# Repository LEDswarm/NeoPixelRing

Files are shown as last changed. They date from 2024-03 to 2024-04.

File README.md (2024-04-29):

led_board_banner3

# A custom NeoPixel ring for LEDswarm controllers

This repository contains the 3D model, schematic and PCB design of the circular NeoPixel boards designed for use with the LEDswarm controller enclosure. The design is inspired by NeoPixel Jewels, except this a special daughter board designed to mate with controller mainboards within [the 3D-printed enclosure](https://github.com/LEDswarm/enclosure).

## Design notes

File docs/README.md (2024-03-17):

# A custom NeoPixel ring with a board-to-board USB-C socket

A custom circular PCB with a ring of eight cool-white SK6812 RGBW LEDs on it, used to illuminate the diffusor of an LEDswarm controller enclosure.

Many of the first experiments were done with the NeoPixel Jewels by Adafruit, which is basically a short LED strip of seven NeoPixels arranged in a hexagon and with one in the middle. However, that board turned out to be not easily adaptable to a connector-based, board-to-board design, so we decided to use USB-C to mate the boards and directly use a few pins of a USB-C connection to transfer +5V, the data signal, ground and an optional I2C connection for additional peripherals.

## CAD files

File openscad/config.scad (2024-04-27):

/////
//     General configuration
/////

$fn = 96;

/////
//     PCB dimensions
/////

pcb_diameter = 28.5;
pcb_thickness = 1.6;

pcb_radius = pcb_diameter / 2;
pcb_color = [0.2, 0.2, 0.2];
// Height of the SMD pads on the circuit board
smd_pad_height = 0.035;


/////
//     PCB drill holes
/////

pcb_screw_diameter = 2.0;
pcb_screw_hole_diameter = 2.0;

// How far to inset the screw holes from the edge of the PCB
pcb_screw_hole_inset = 0.7;

/////
//     LED dimensions
/////

// Size is 5050, so five by five millimeters
led_size = 5.0;
led_height = 1.0;

// How many LEDs to place in the circle
num_leds = 8;
// Set rotation phase of the LEDs
led_starting_angle = (360 / num_leds) / 2;

// How far outwards to push the LEDs in their octagonal arrangement
led_radius= 20.3;

// How far outwards to put the capacitors
led_capacitor_length = 4 / 2.54;
led_capacitor_width = 2 / 2.54;
led_capacitor_height = 2 / 2.54;

led_capacitor_color = [0.7, 0.45, 0];

led_text_num_radius = 12.5;

led_capacitor_radius= 24.5;
led_capacitor_starting_angle = 45.0;
// Make sure to respect screw holes when placing eight possible capacitor spots on circle.
led_capacitor_distribution = [true, true, true, false, true, true, true, false];

// How many millimeters the pad is inset from the edge of the LED.
led_smd_pad_inset = 0.4;
// How many millimeters the square pad extends out to the side from the LED edge.
led_smd_pad_outset = 0.2;
led_smd_pad_width = 1.5;
led_smd_pad_height = 1.0;


/////
//     SMD mount dimensions for female USB-C socket
/////

// Ensures the vias are aligned to the through holes correctly.
via_correction_factor = 0.07;

// Vertical offset of the USB-C port from the center of the PCB, to accomodate for the breadboard pin vias.
male_usb_c_height = 2.4;
//usb_vertical_offset = pcb_thickness / 2 + male_usb_c_height / 2;
// The male connector is vertically centered.
usb_vertical_offset = 0;

echo("USB vertical offset: ", usb_vertical_offset);

// Pin hole size for the USB-C port
usb_pin_hole_diameter = 0.9;

// Distance between the centers of the two pin holes
usb_pin_hole_spacing = 10.8;

// Horizontal distance between the centers of two USB-C through-hole pins
usb_through_hole_horizontal_spacing = 8.45;
usb_through_hole_vertical_spacing = 4.04;

// Dimensions of the cut holes for the USB-C port
usb_through_hole_width = 1.85;
usb_through_hole_height = 1.0;
usb_through_hole_inner_width = 1.3;
usb_through_hole_inner_height = 0.6;
usb_through_hole_inner_border_radius = usb_through_hole_inner_height / 2;
usb_through_hole_border_radius = usb_through_hole_height / 2;

// Dimensions and extents of the SMD pads for the USB-C port
usb_smd_pad_height = 1.6;
usb_smd_pad_width = 0.55;
// Horizontal distance between the centers of two USB-C SMD pads
usb_smd_pad_horizontal_spacing = 1.0;
// How many pads to place for single contact row in the USB-C SMD connector
usb_smd_pad_num_h = 8;

// Total vertical extent of the USB SMD pads, or the distance from the top edge of an upper SMD pad to the bottom edge of a lower SMD pad.
usb_smd_vertical_extent = 3.9;
// Horizontal spacing between the centers of the outermost SMD contacts.
usb_smd_horizontal_spacing = 7.0;

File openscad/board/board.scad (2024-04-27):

include <../config.scad>;

include <../capacitor.scad>;
include <../smd/usb_contacts.scad>;

// The circular circuit board of the NeoPixel ring.
module BoardPcb () {
    difference () {
        union () {
            color(pcb_color)
            cylinder(d=pcb_diameter, h=pcb_thickness, center = true);
            
            translate([0, -usb_vertical_offset, 0])
            usb_smd();
        }

        BoardDrillHoles();
    }

    //LedCircularArrangement();
    //CapacitorCircularArrangement();
    //color([0.7, 0.3, 0.3])
    //LedSilkscreenCircularArrangement();
}

module BoardDrillHoles () {
    BoardScrewHole();

    mirror([1, 0, 0])
    BoardScrewHole();

    // usb_pin_hole_spacing
    BoardUsbPinhole();
    mirror([1, 0, 0])
    BoardUsbPinhole();

    translate([0, vertical_center, -3])
    usb_smd_corner_cutouts();
}

module BoardScrewHole () {
    echo("Screw hole at ", pcb_diameter / 2 - pcb_screw_hole_inset - pcb_screw_hole_diameter / 2, " 0 -1");
    translate([pcb_diameter / 2 - pcb_screw_hole_inset - pcb_screw_hole_diameter / 2, 0, -1])
    cylinder(d=pcb_screw_hole_diameter, h=pcb_thickness + 3, center = true);
}

module BoardUsbPinhole () {
    translate([usb_pin_hole_spacing / 2, -usb_vertical_offset, -1])
    cylinder(d=usb_pin_hole_diameter, h=pcb_thickness + 3, center = true);
}

module LedCircularArrangement () {
    for (i = [0 : num_leds - 1]) {
        current_angle = i * (360.0 / num_leds);
        x = led_radius / 2 * cos(led_starting_angle + current_angle);
        y = led_radius / 2 * sin(led_starting_angle + current_angle);
        echo("LED ", i, " at X ", x, "   Y ", y, "     Angle ", led_starting_angle + current_angle);

        translate([x, y, 0])
        led(rotation = led_starting_angle + current_angle);
    }
}

module CapacitorCircularArrangement () {
    for (i = [0 : num_leds - 1]) {
        current_angle = i * (360.0 / num_leds);
        x = led_capacitor_radius / 2 * cos(led_capacitor_starting_angle + current_angle);
        y = led_capacitor_radius / 2 * sin(led_capacitor_starting_angle + current_angle);

        echo("Capacitor ", i, " at X ", x, "   Y ", y, "     Angle ", led_capacitor_starting_angle + current_angle);

        if (led_capacitor_distribution[i]) {
            translate([x, y, 1.2])
            Capacitor(rotation = led_capacitor_starting_angle + current_angle);
        }
    }
}

led_vdd_via_circle_radius = 23.0;

module LedSilkscreenCircularArrangement () {
    for (i = [0 : num_leds - 1]) { // Condition: num_leds - 1
        current_angle = i * (360.0 / num_leds) + 180;
        x = led_vdd_via_circle_radius / 2 * cos(led_starting_angle + current_angle);
        y = led_vdd_via_circle_radius / 2 * sin(led_starting_angle + current_angle);

        echo("LED Silkscreen Number ", i, " at X ", x, "   Y ", y, "     Angle ", led_starting_angle - 20 + current_angle);

        translate([x - 0.2, y - 0.2, 0])
        cylinder(h=4, d=1);

        translate([x + 1.1, y - 3.1, 0])
        cylinder(h=4, d=1);
    }
}

module led (rotation = 0.0) {
    rotate(rotation, [0, 0, 1])
    translate([0, 0, pcb_thickness / 2])
    LED_5050_RGBW();
}

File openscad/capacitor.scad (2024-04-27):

module Capacitor (rotation = 0.0) {
    color(led_capacitor_color)
    rotate([0, 0, rotation])
    cube([led_capacitor_length, led_capacitor_width, led_capacitor_height], center=true);
}

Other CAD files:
openscad/led.scad
openscad/main.scad
openscad/smd/usb_contacts.scad

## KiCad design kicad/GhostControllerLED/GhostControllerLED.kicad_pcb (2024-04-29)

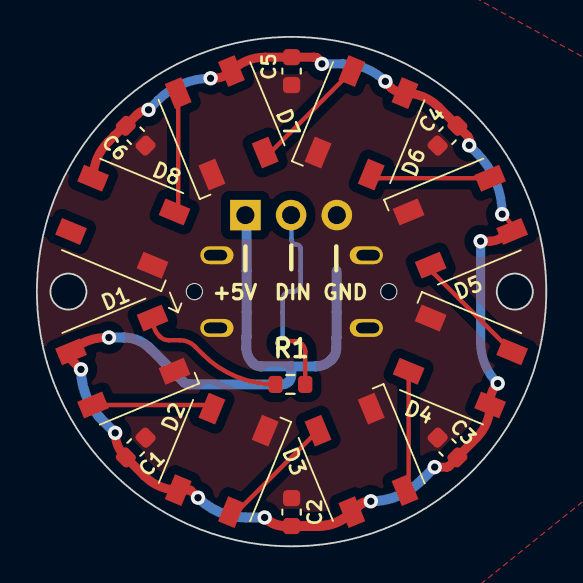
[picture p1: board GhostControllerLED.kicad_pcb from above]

Board: 2 copper layers, 28.3 x 28.3 mm, 16 parts (1 on the bottom side), 11 nets.

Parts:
1: SK6812; LED_SK6812_PLCC4_5.0x5.0mm_P3.2mm
C1, C2, C3, C4, C5, C6: 100nF; C_0603_1608Metric
D2, D3, D4, D5, D6, D7, D8: SK6812; LED_SK6812_PLCC4_5.0x5.0mm_P3.2mm
NoUSB: Female LED Connector (No USB); Hanbo-Electronic-MC-118LS-H100 USB-C Socket
R1: 220; R_0603_1608Metric

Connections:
GND: 1.1 (VSS), C1.1, C2.1, C3.1, C4.1, C5.1, C6.1, D2.1 (VSS), D3.1 (VSS), D4.1 (VSS), D5.1 (VSS), D6.1 (VSS), D7.1 (VSS), D8.1 (VSS), NoUSB.1, NoUSB.2, NoUSB.3, NoUSB.A1 (GND), NoUSB.A12 (GND), NoUSB.B1 (GND), NoUSB.B12 (GND)
unnamed: 1.2 (DIN), R1.1
unnamed: 1.4 (DOUT), D2.2 (DIN)
unnamed: 1.3 (VDD), C1.2, C2.2, C3.2, C4.2, C5.2, C6.2, D2.3 (VDD), D3.3 (VDD), D4.3 (VDD), D5.3 (VDD), D6.3 (VDD), D7.3 (VDD), D8.3 (VDD), NoUSB.A4 (VBUS), NoUSB.A9 (VBUS), NoUSB.B4 (VBUS), NoUSB.B9 (VBUS)
unnamed: D2.4 (DOUT), D3.2 (DIN)
unnamed: D3.4 (DOUT), D4.2 (DIN)
unnamed: D4.4 (DOUT), D5.2 (DIN)
unnamed: D5.4 (DOUT), D6.2 (DIN)
unnamed: D6.4 (DOUT), D7.2 (DIN)
unnamed: D7.4 (DOUT), D8.2 (DIN), D8.4 (DOUT)
unnamed: NoUSB.A6 (D+), NoUSB.B6 (D+), R1.2

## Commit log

2024-03-17 feat: start working on a structured approach to 3d modeling the neopixel board
    [board.scad, config.scad, led.scad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]
2024-03-17 feat: add programmatic distribution of leds around the tangential of a circle
    [board.scad]
2024-03-17 config: add PCB color and circle diameter for tangential LED placement
    [config.scad]
2024-03-17 chore: wrap led base into a module and mirror smd pins two by two
    [led.scad]
2024-03-17 chore: adjust led radius to have 0.6mm distance to the edge of the board from smd pad
    [config.scad]
2024-04-27 feat: push current state
    [board.scad, capacitor.scad, config.scad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]
2024-04-28 feat: add KiCad files
    [GhostControllerLED.kicad_pcb, GhostControllerLED.kicad_sch, GhostControllerLEDRadialLayout.kicad_pcb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]
2024-04-28 doc: add image from KiCad
2024-04-29 chore: add copper fill zones
    [GhostControllerLED.kicad_pcb]
2024-04-29 feat: finalize LED board design to 1.0
    [GhostControllerLED.kicad_pcb]
2024-04-29 feat: generate gerber files
    [GhostControllerLED-B_Cu.gbl, GhostControllerLED-B_Cu.gbr, GhostControllerLED-B_Mask.gbr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]

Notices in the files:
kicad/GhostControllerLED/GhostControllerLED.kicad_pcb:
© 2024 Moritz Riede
